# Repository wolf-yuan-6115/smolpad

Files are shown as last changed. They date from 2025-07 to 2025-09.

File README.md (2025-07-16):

# SmolPad

A slightly customized PCB keyboard with a case. 

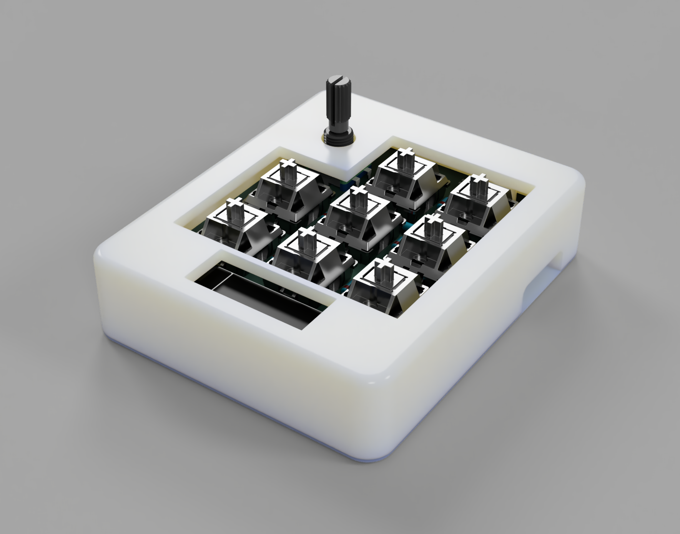
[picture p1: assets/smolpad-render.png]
SmolPad Render

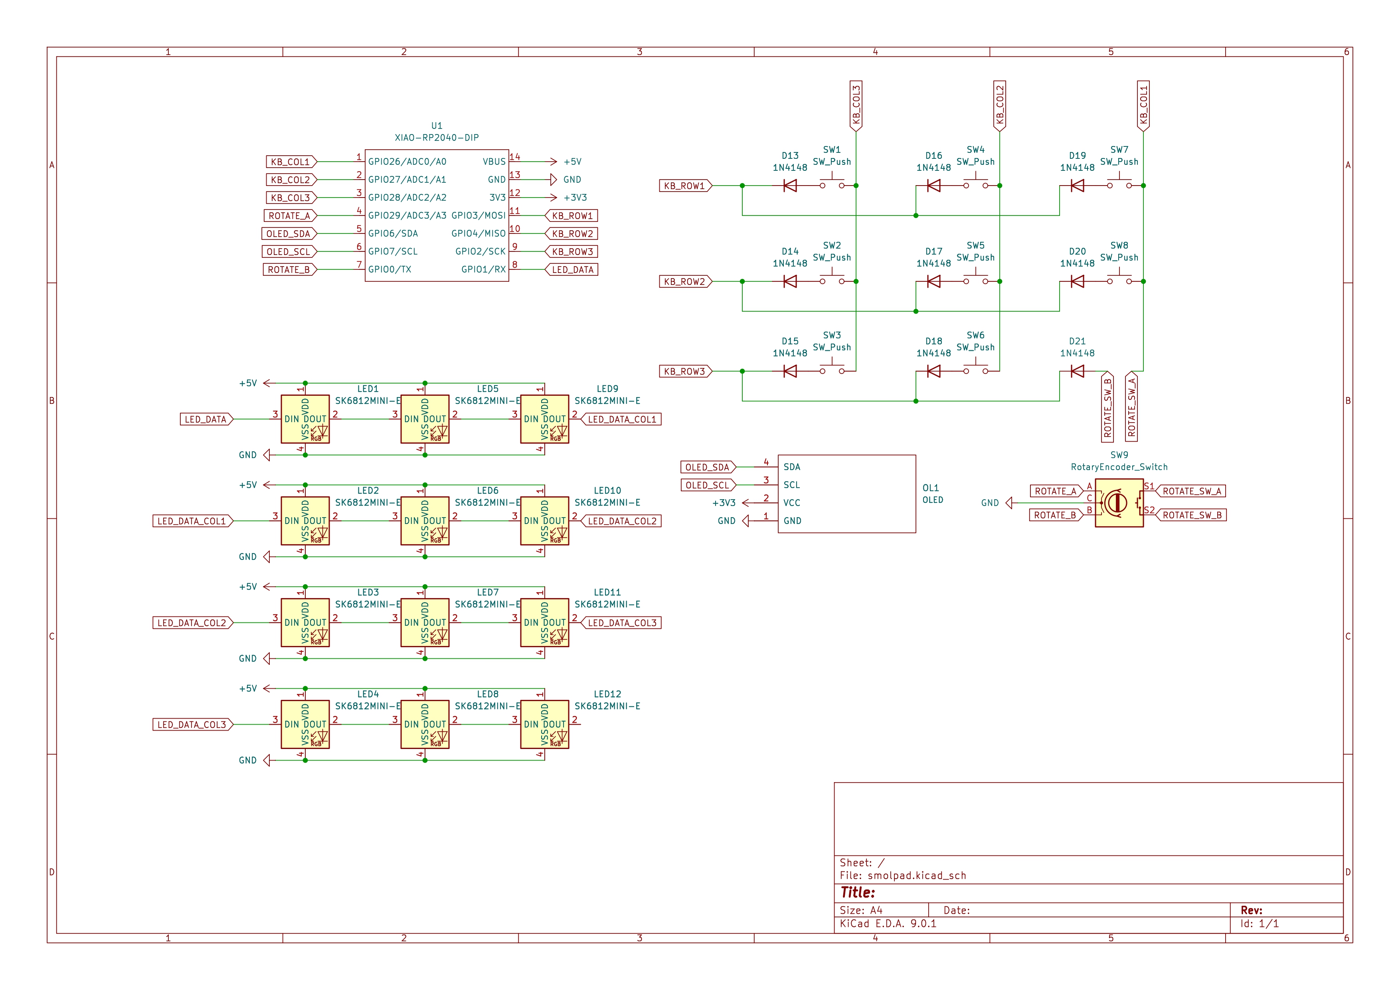
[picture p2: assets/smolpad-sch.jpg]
SmolPad Schematic


> [Schematic download](pcb/schematic.pdf)

> Bottom lighting design is inspired by [samdev-7/squarepad](https://github.com/samdev-7/squarepad)
>
> Uses external 3D component, https://makerworld.com/en/models/628840-ec11-encoder-knob#profileId-593261.

## Bill of material

| Item | QTY. |
|---|:----:|
| Seeed Xiao RP2040 | 1 |
| SK6812 mini-e | 12 |
| MX style switches | 8 |
| EC11E Rotatory encoder | 1 |
| 0.91" OLED screen | 1 |
| 1N4148 Diode | 9 |

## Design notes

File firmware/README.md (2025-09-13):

# smolpad/firmware

The firmware that powers the SmolPad. It currently uses QMK, to reproduce, simply setup QMK environment and copy this folder, rename it to `smolpad` and copy to `qmk_firmware/keyboards/`.

After that, you could compile with `qmk compile -kb smolpad -km default`

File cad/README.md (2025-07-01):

# smolpad/cad

This directory contains one file that contained whole SmolPad. From PCB, Seeed Xiao to case itself.

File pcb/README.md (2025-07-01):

# smolpad/pcb

This folder contains everything that's designed with KiCad.

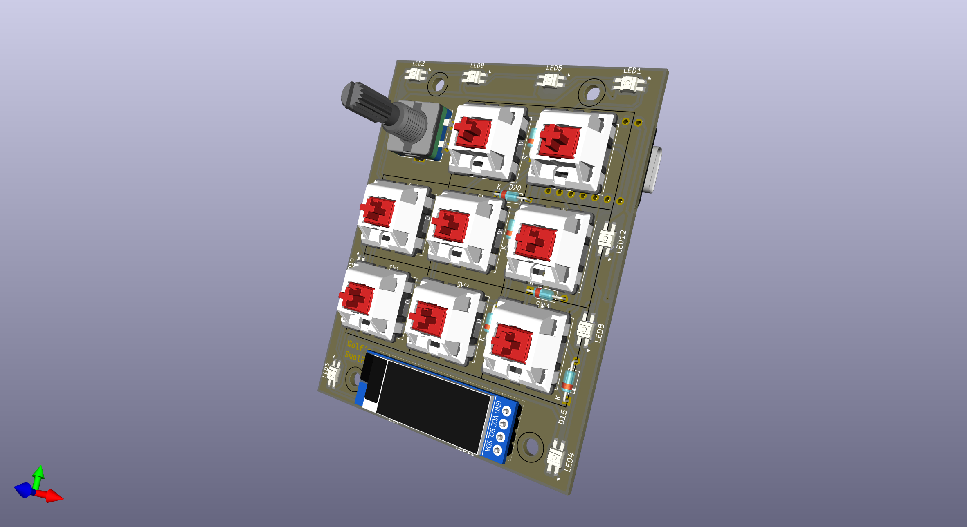
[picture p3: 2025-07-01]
assets/smolpad-pcb.png

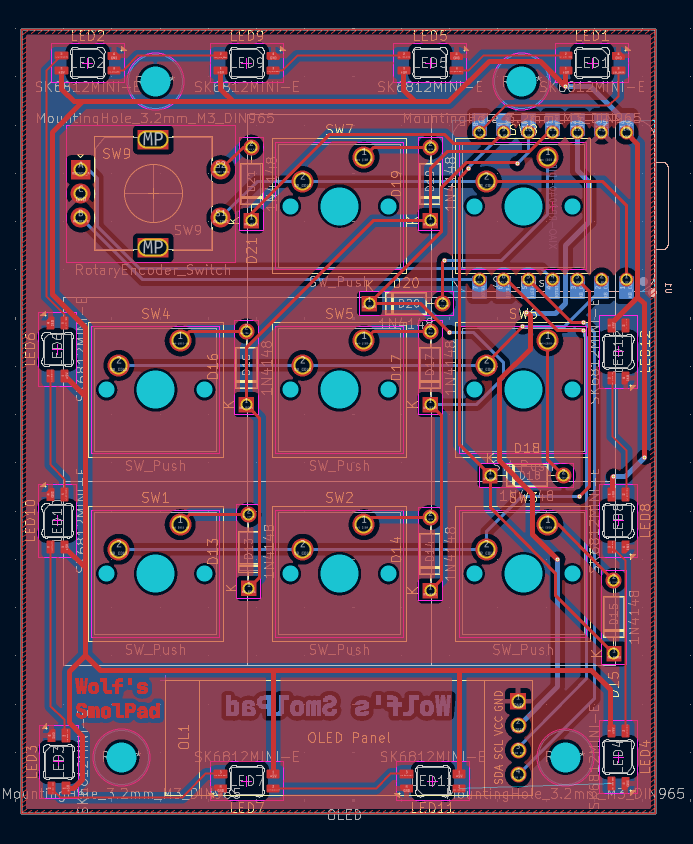
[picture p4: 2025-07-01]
assets/smolpad-pcbr.png

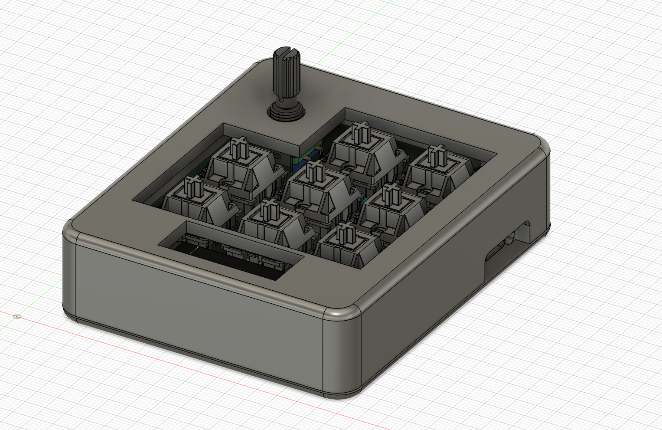
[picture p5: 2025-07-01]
assets/smolpad-cad.png

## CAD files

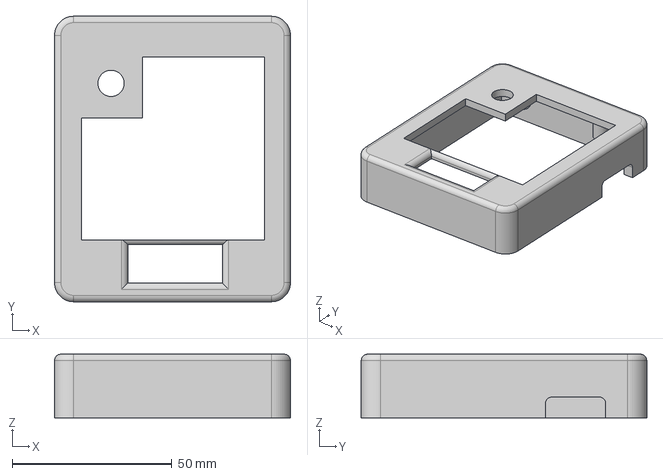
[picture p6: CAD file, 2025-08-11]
production/top.step
73.8 x 89.2 x 19.9 mm

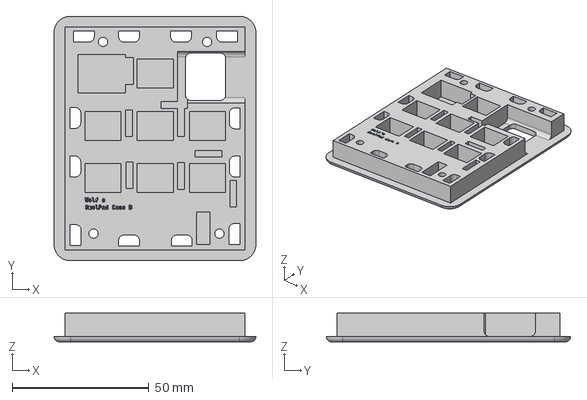
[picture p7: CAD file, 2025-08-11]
production/bottom.step
73.8 x 89.2 x 10.5 mm

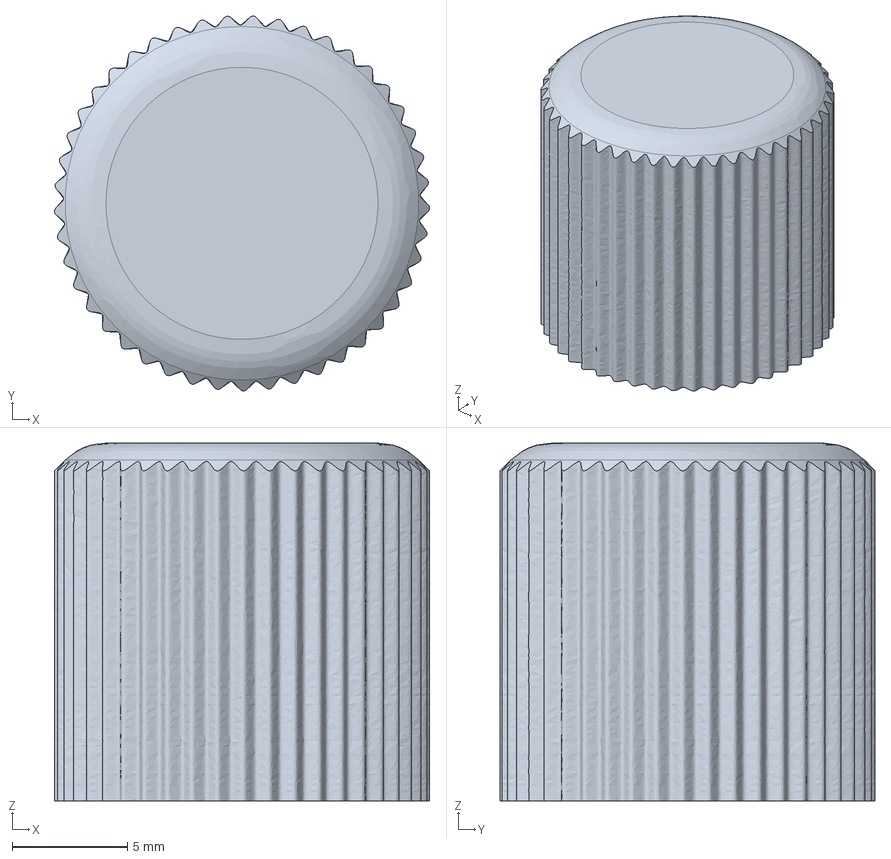
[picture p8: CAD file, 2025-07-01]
production/knob.stp
16.3 x 16.2 x 15.5 mm

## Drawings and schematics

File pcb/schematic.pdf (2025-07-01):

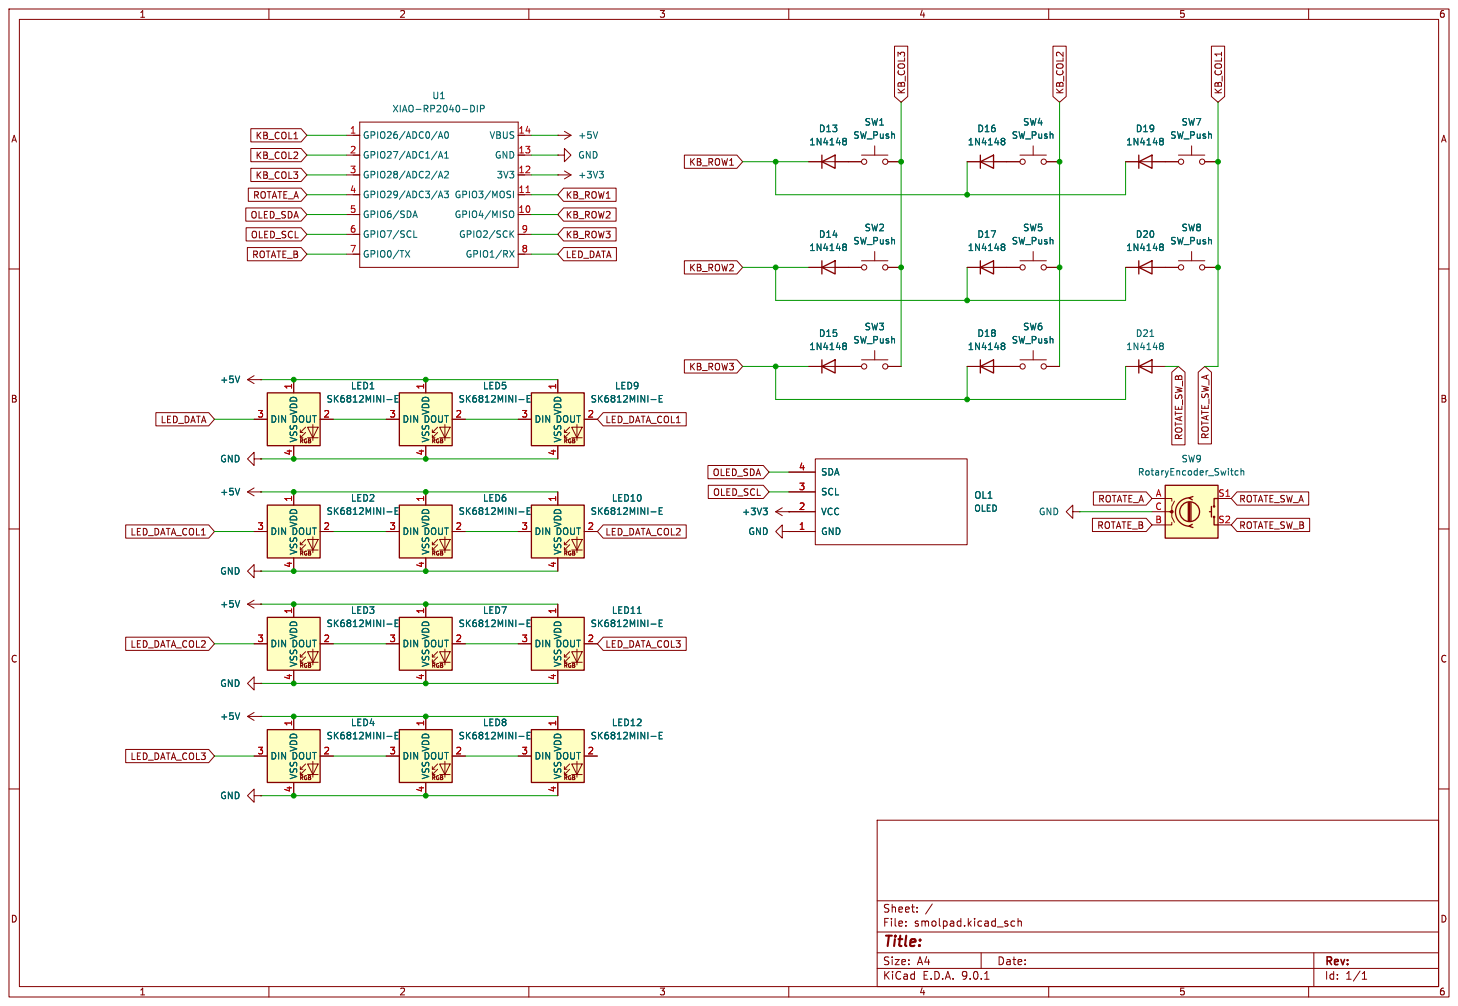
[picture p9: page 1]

Id: 1/1 Title: File: smolpad.kicad_sch Sheet: / +5V GND

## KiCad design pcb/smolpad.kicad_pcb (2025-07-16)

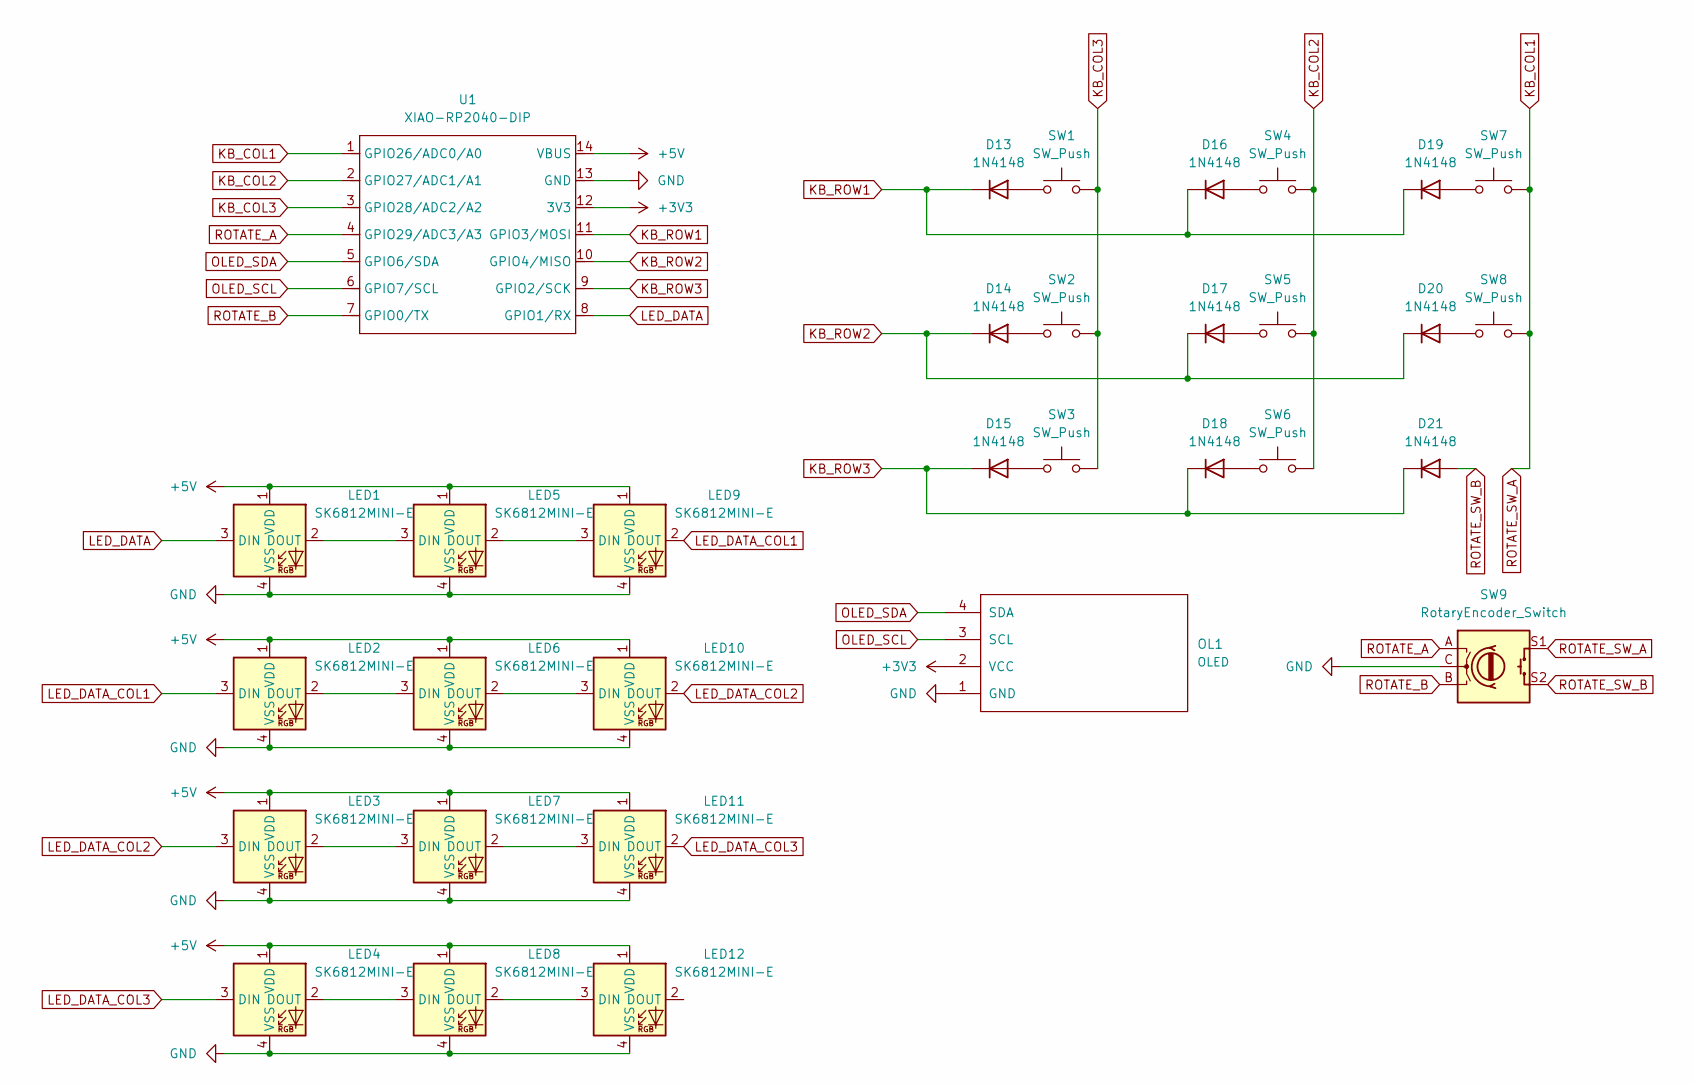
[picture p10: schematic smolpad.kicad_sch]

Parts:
D13, D14, D15, D16, D17, D18, D19, D20, D21: 1N4148; D_DO-35_SOD27_P7.62mm_Horizontal
LED1, LED2, LED3, LED4, LED5, LED6, LED7, LED8, LED9, LED10, LED11, LED12: SK6812MINI-E; LED_6028R
OL1: OLED; SSD1306-0.91-OLED-4pin-128x32
SW1, SW2, SW3, SW4, SW5, SW6, SW7, SW8: SW_Push; SW_Cherry_MX_1.00u_PCB_1
SW9: RotaryEncoder_Switch; RotaryEncoder_Alps_EC11E-Switch_Vertical_H20mm
U1: XIAO-RP2040-DIP

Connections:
+3V3: OL1.2 (VCC), U1.12 (3V3)
+5V: LED1.1 (VDD), LED2.1 (VDD), LED3.1 (VDD), LED4.1 (VDD), LED5.1 (VDD), LED6.1 (VDD), LED7.1 (VDD), LED8.1 (VDD), LED9.1 (VDD), LED10.1 (VDD), LED11.1 (VDD), LED12.1 (VDD), U1.14 (VBUS)
GND: LED1.4 (VSS), LED2.4 (VSS), LED3.4 (VSS), LED4.4 (VSS), LED5.4 (VSS), LED6.4 (VSS), LED7.4 (VSS), LED8.4 (VSS), LED9.4 (VSS), LED10.4 (VSS), LED11.4 (VSS), LED12.4 (VSS), OL1.1 (GND), SW9.C, U1.13 (GND)
KB_COL1: SW7.2, SW8.2, SW9.S1, U1.1 (GPIO26/ADC0/A0)
KB_COL2: SW4.2, SW5.2, SW6.2, U1.2 (GPIO27/ADC1/A1)
KB_COL3: SW1.2, SW2.2, SW3.2, U1.3 (GPIO28/ADC2/A2)
KB_ROW1: D13.1 (K), D16.1 (K), D19.1 (K), U1.11 (GPIO3/MOSI)
KB_ROW2: D14.1 (K), D17.1 (K), D20.1 (K), U1.10 (GPIO4/MISO)
KB_ROW3: D15.1 (K), D18.1 (K), D21.1 (K), U1.9 (GPIO2/SCK)
LED_DATA: LED1.3 (DIN), U1.8 (GPIO1/RX)
LED_DATA_COL1: LED2.3 (DIN), LED9.2 (DOUT)
LED_DATA_COL2: LED3.3 (DIN), LED10.2 (DOUT)
LED_DATA_COL3: LED4.3 (DIN), LED11.2 (DOUT)
unnamed: D13.2 (A), SW1.1
unnamed: D14.2 (A), SW2.1
unnamed: D15.2 (A), SW3.1
unnamed: D16.2 (A), SW4.1
unnamed: D17.2 (A), SW5.1
unnamed: D18.2 (A), SW6.1
unnamed: D19.2 (A), SW7.1
unnamed: D20.2 (A), SW8.1
unnamed: LED1.2 (DOUT), LED5.3 (DIN)
unnamed: LED2.2 (DOUT), LED6.3 (DIN)
unnamed: LED3.2 (DOUT), LED7.3 (DIN)
unnamed: LED4.2 (DOUT), LED8.3 (DIN)
unnamed: LED5.2 (DOUT), LED9.3 (DIN)
unnamed: LED6.2 (DOUT), LED10.3 (DIN)
unnamed: LED7.2 (DOUT), LED11.3 (DIN)
unnamed: LED8.2 (DOUT), LED12.3 (DIN)
OLED_SCL: OL1.3 (SCL), U1.6 (GPIO7/SCL)
OLED_SDA: OL1.4 (SDA), U1.5 (GPIO6/SDA)
ROTATE_A: SW9.A, U1.4 (GPIO29/ADC3/A3)
ROTATE_B: SW9.B, U1.7 (GPIO0/TX)
ROTATE_SW_B: D21.2 (A), SW9.S2

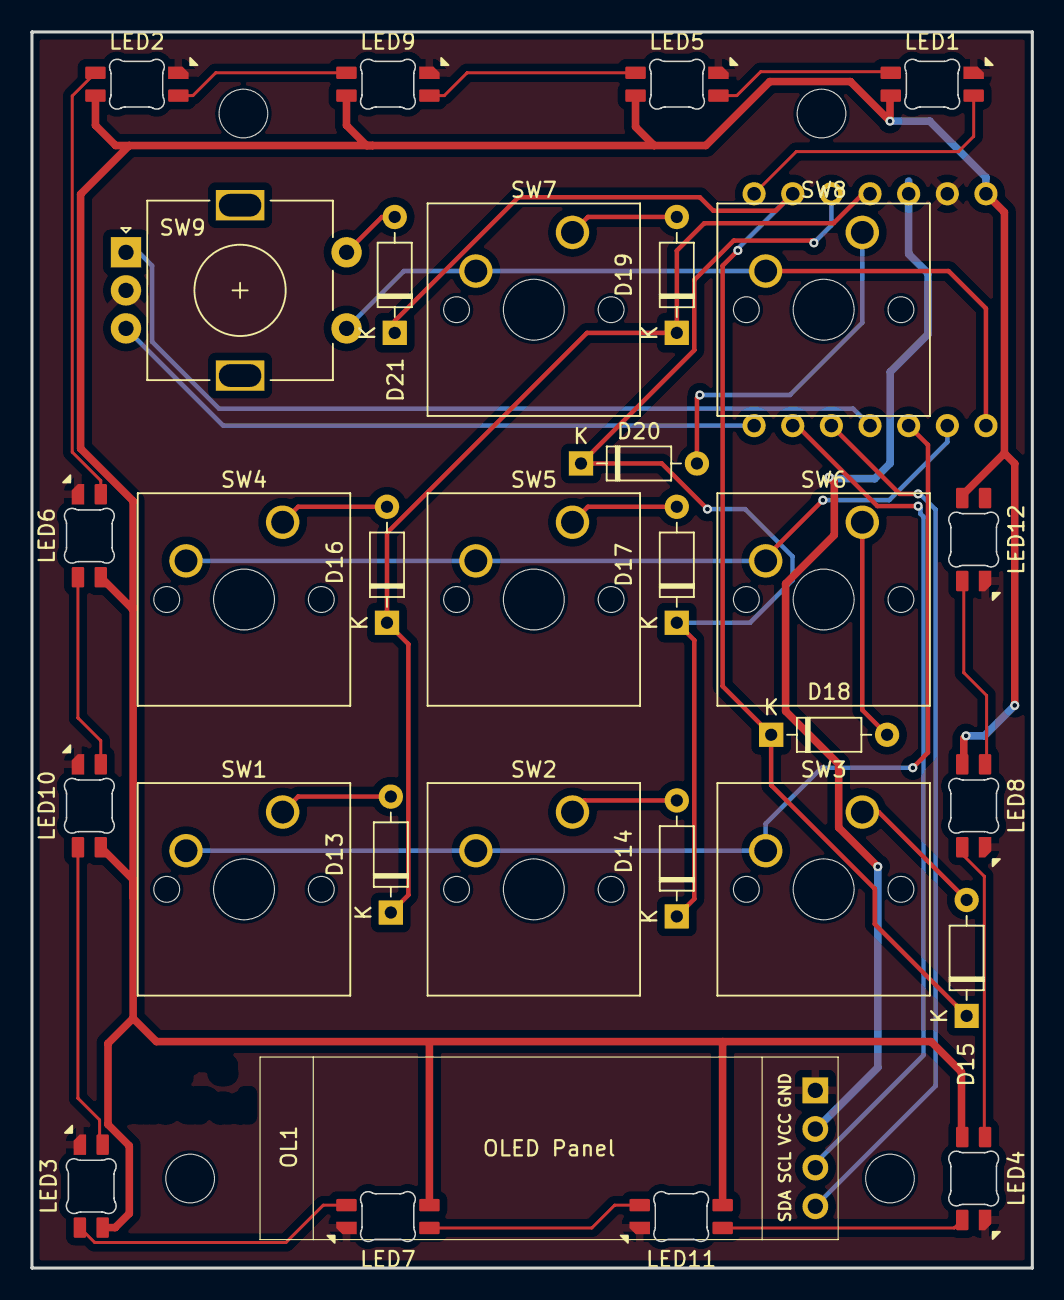
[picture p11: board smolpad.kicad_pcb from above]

Board: 2 copper layers, 65.8 x 81.2 mm, 32 parts (1 on the bottom side), 34 nets.

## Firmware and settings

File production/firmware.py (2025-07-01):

# A "should" work firmware, might subject to change in the future

import board
from kmk.kmk_keyboard import KMKKeyboard
from kmk.keys import KC
from kmk.scanners import DiodeOrientation
from kmk.modules.encoder import EncoderHandler
from kmk.modules.oled import OLED, OLEDScreen
from kmk.extensions.rgb import RGB

keyboard = KMKKeyboard()

keyboard.col_pins = (board.GP26, board.GP27, board.GP28)  # KB_COL1~3
keyboard.row_pins = (board.GP3, board.GP4, board.GP2)  # KB_ROW1~3
keyboard.diode_orientation = DiodeOrientation.COL2ROW

# Layout on the PCB:
#
# EC11 7 8
#   4  5 6
#   1  2 3

keyboard.keymap = [
    [
        KC.LEFT, KC.RIGHT, KC.NO,
        KC.F13, KC.F15, KC.F17,
        KC.F14, KC.F16, KC.F18
    ]
]

encoder = EncoderHandler()
encoder.pins = ((board.GP0, board.GP29, None))  # ROTATE_A, ROTATE_B, no switch
encoder.map = [
    (lambda: keyboard.send(KC.VOLD), lambda: keyboard.send(KC.VOLU))
]
keyboard.modules.append(encoder)

i2c_bus = busio.I2C(board.GP7, board.GP6)
display_driver = SSD1306(
    i2c=i2c_bus,
)

display = Display(
    display=display_driver,
    entries=[
        TextEntry(text="SmolPad", x=0, y=0),
        TextEntry(text="I think it's working now", x=0, y=32, y_anchor='B'),
    ],
    width=128,
    height=32,
    dim_time=10,
    dim_target=0.2,
    off_time=60,
    brightness=1,
)

rgb = RGB(
    pixel_pin     = board.GP10,
    num_pixels    = 12,
    hue_default   = 240,
    sat_default   = 255,
    val_default   = 100,
    animation_speed = 2
)

keyboard.extensions.append(rgb)
rgb.effect = "knight"


if __name__ == '__main__':
    keyboard.go()

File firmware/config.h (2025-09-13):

#define I2C_DRIVER I2CD1
#define I2C1_SCL_PIN GP7
#define I2C1_SDA_PIN GP6
#define OLED_FADE_OUT
#define OLED_FADE_OUT_INTERVAL 3

#define WS2812_DI_PIN GP1
#undef RGBLIGHT_LED_COUNT
#define RGBLIGHT_LED_COUNT 12
#define RGBLIGHT_LIMIT_VAL 45
#define RGBLIGHT_DEFAULT_SAT 0
#define RGBLIGHT_SLEEP

#define ENCODER_A_PINS { GP29 }
#define ENCODER_B_PINS { GP0 }
#define ENCODER_RESOLUTIONS { 4 }

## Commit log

2025-07-01 feat: add cad files
2025-07-01 feat: add pcb
    [smolpad.kicad_pcb, smolpad.kicad_sch]
2025-07-01 feat: add stp files for 3d printing
    [bottom.step, knob.stp, up.step]
2025-07-01 feat: add gerber
2025-07-01 feat: add schematic to readme
2025-07-01 feat: update oled display driver
2025-07-01 feat: add branding to case
    [bottom.step, top.step, up.step]
2025-07-01 fix: increase hole length to prevent pcb wiggle
    [bottom.step, top.step]
2025-07-01 fix: unconnected trace on pcb
    [smolpad.kicad_pcb]
2025-07-16 feat: update board
    [smolpad.kicad_pcb]
2025-08-11 feat: update case 3d file
    [bottom.step, top.step]
